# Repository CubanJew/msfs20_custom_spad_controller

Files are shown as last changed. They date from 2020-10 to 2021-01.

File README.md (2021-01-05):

# msfs20_custom_spad_controller
Microsoft Flight Simulator 2020 - Custom Flight Panel Controller

### Description:
Custom control panel for Microsoft Flight Simulator 2020 using SPAD.neXt as interface between game and Arduino microcontroller. Designed with A320 in mind. Panel is meant to be mounted to the side of Logitech G Flight Simulator Panel bracket. 

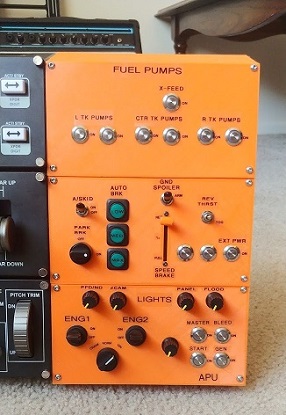
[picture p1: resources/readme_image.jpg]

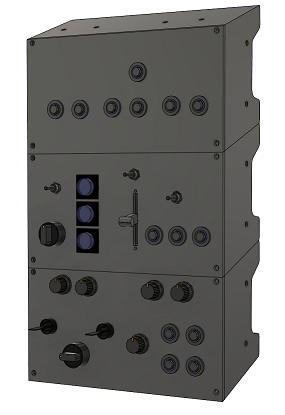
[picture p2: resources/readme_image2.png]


Supports:
- **17 pushbutton with LED** (LED is controlled by state of control in the game).
	_[fuel pumps 1-6, cross-feed pump, APU-master, APU-start, APU-bleed air, APU-gen, external power, auto-brake level control (low + med + max), x2 TBD (spare)]_
	
- **5 toggle switches**
	_[anti-skid, ground spoiler arm, engine 1 + 2 master starters, reverse throttle toggle]_
	
- **2 selector switches**
	_[engine mode switch (crank/normal/ignition), parking break]_
- **6 potentiometers** (5 rotary + 1 slide)
	_[lights: PFD/ND/FD, ECAM, flood, panel, x1 TBD (spare);  speed brake (slide pot)]_
- **1 foot pedal switch**
	_[brake pedals]_

Control board utilizes x3 MCP23017 I2C I/O expander ICs to provide control over 48 distinct inputs/outputs with just 2 Arduino pins. For LED outputs, each MCP23017 I/O pin is connected to an LED with a series resistor. For button inputs, each button is connected directly to an MCP23017 I/O pin, with an internal pull-up resistor enabled via software. All buttons are daisy-chained to ground on one side, and therefore no additional components are necessary for handling button inputs. Note that the pushbutton LEDs are controlled independently of the pushbutton meaning that the LED light state will reflect the state of the respective control in the game whether you cycle the control in the game or via the control panels physical button. The Arduino microcontrller handles detecting button presses and controls LED lights, and utilizes a 2-way serial connection with SPAD.neXT to interface with the game. 

### Installation Instructions:
1. Build the control interface board by following [schematics](https://github.com/CubanJew/msfs20_custom_spad_controller/blob/main/Hardware/Electrical/Schematic.pdf).

2. 3D print STL files located in `/Hardware/Panel 3D Files/STL/`. You will need 3 Brackets, 1 Slide Potentiometer Lever Hat, and one of each of the three faceplates. Use soldering iron to heat insert four M3-4mm knurled brass inserts into each bracket's corner faceplate mounting holes and secure each faceplate to bracket with four M3-6mm bolts. Note that bracket top mounting holes are misaligned relative to the bottom mounting holes. If you wish to attach the three brackets vertically, drill new upper mounting holes to 2 of 3 the brackets. Bracket mounting hole alignment will be fixed in future. 

3. Install buttons/potentiometers on to faceplate holes (note: you will need to use a deburring tool to slightly enlarge the component holes as there is very little tolerance) and wire up connections between panel and control interface board. Daisy-chain switch/pot grounds together for each panel. Refer to [Bill of Materials](https://github.com/CubanJew/msfs20_custom_spad_controller/blob/main/Hardware/Bill%20of%20Materials.txt) for parts information. Reference [I/O connection summary table](https://github.com/CubanJew/msfs20_custom_spad_controller/blob/main/Hardware/Electrical/IO%20Table.JPG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) and [schematic](https://github.com/CubanJew/msfs20_custom_spad_controller/blob/main/Hardware/Electrical/Schematic.pdf).

4. To upload microcontroller firmware, install PlatformIO IDE and add `/Software/AVR/FLIGHT SIM SPAD INTERFACE/` as new folder project. Upload code to your Arduino Pro Micro. 

5. Add control interface board to SPAD.neXt as a new Serial device to SPAD.neXt under settings->Devices->Serial Devices->"Add New Device" with the following settings:

	> Serial Port = = your USB COM port
	
	> Speed = 115200
	
	> Enable DTR = ON
	
	> 32 Bit = OFF
	
   Save settings and restart SPAD.neXt. Verify control interface board serial device is connected to SPAD.neXt by going to panels->SERIAL COMXX and selecting "Show Log". If it is not connected press "Connect".
   
6. Add each of the scripts included in `/Software/SPAD.next Configuration/` folder to SPAD.neXt script panel.

7. If you have flybywiresim's "A32NX" mod installed you will need to update the mod's light potentiometer indices in order to make the light potentiometers work [(reference)](https://github.com/flybywiresim/a32nx/issues/1202). Install Autohotkey and run script named `A32NX Pot ID Fix.ahk`located in `/Software/A32NX Pot ID Fix/`

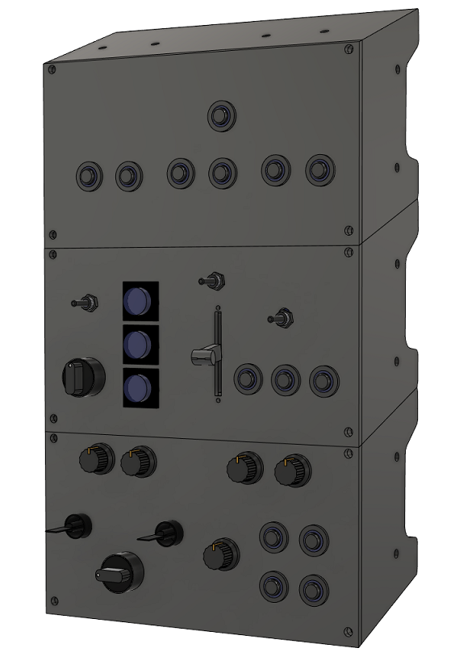
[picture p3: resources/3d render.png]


References:

- [Fusion 360 3D Design File](https://a360.co/2SDgtfb) or `/Hardware/Panel 3D Files/FLIGHT SIM COCKPIT v27.f3d`
- [Schematic](https://github.com/CubanJew/msfs20_custom_spad_controller/blob/main/Hardware/Electrical/Schematic.pdf)
- [I/O Reference Table](https://github.com/CubanJew/msfs20_custom_spad_controller/blob/main/Hardware/Electrical/IO%20Table.JPG) 
- [Bill of Material](https://github.com/CubanJew/msfs20_custom_spad_controller/blob/main/Hardware/Bill%20of%20Materials.txt)
- [Project Photo Gallery](https://imgur.com/a/4q6AOHk)

Notes:
1. Faceplate component holes do not have much tolerance; you will need to use a debururing to slightly enlarge the holes. 
2. The size of the microcontroller firmware is large relative to flash program memory of the Arduino Pro Micro. As such, many repeated firmware uploads may randomly corrupt the bootloader. You will need another Arduino or an AVR programmer to reupload the bootloader to allow firmware uploading from your IDE.  

To-do list:
- Fix bracket top mounting hole alignment.
- Combine ground spoiler arm toggle switch and speed brake slide potentiometer into a single physical component.
- Add logic to force game's initial state of anti-skid, ground spoiler arm, and parking brake to match control board when controller is first connected.
- Implement spare 2 buttons and 1 potentiometer on panel. 
- Fabricate front faceplates with backlit labels using http://www.frontpanelexpress.com/ 
- Clean up code
- PWM brightness control for LEDs

Version History:
- 10/14/20: Initial release
- 01/05/21: Update valve indices due to game update for fuel x-feed (from 1 to 3) pushbutton & LED [main.cpp, digital.cpp]; ENG1 & ENG2 MASTER SWITCH (from 6 & 7 to 1 & 2, respectively) SPAD scripts [ENG1 MASTER SW.xml, ENG2 MASTER SW.xml]

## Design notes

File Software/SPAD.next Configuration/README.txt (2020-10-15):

Copy the included scripts in this folder to SPAD.neXt.

These SPAD.neXt scripts are required due to:

1. Ensure fidelity between control state in-game with physical toggle button.

	... or ...

2. Because multiple simulation events are required for a particular digital input (e.g., foot brake pedal).

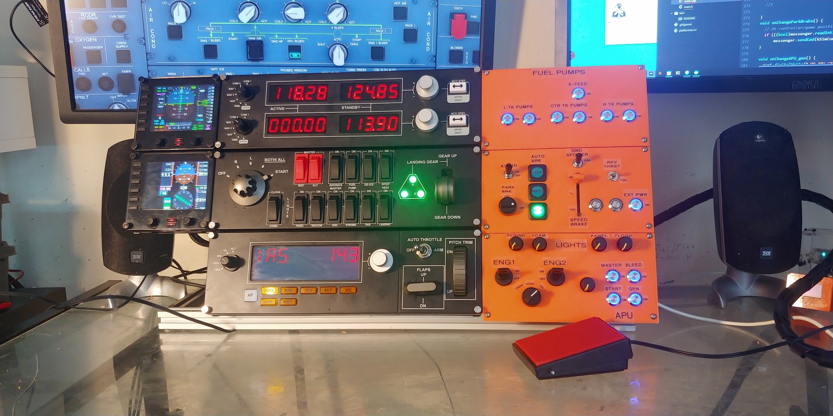
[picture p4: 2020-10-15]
resources/_FINAL - Overview with Lights.jpg

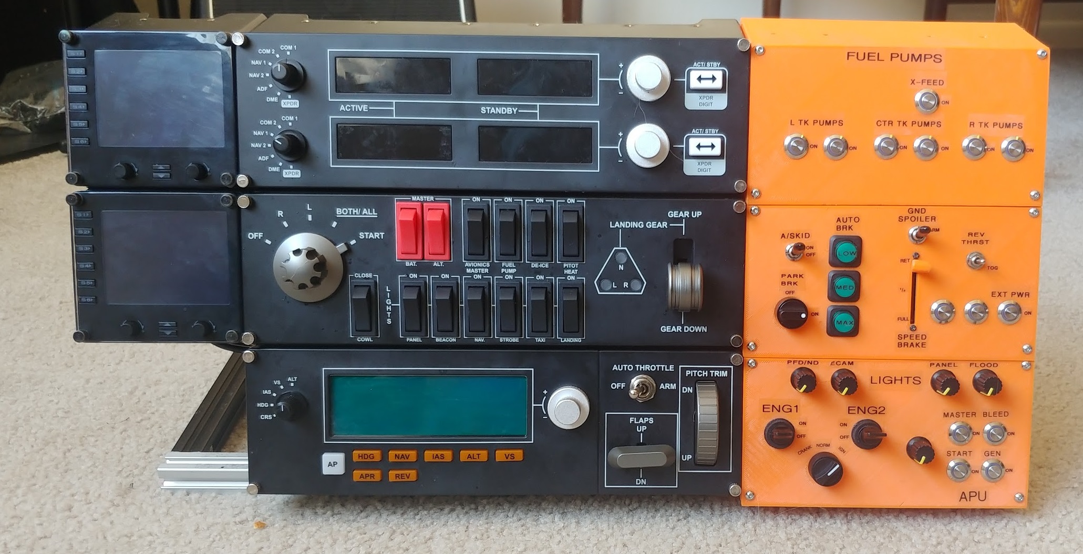
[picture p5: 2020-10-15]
resources/_FINAL - Overview.jpg

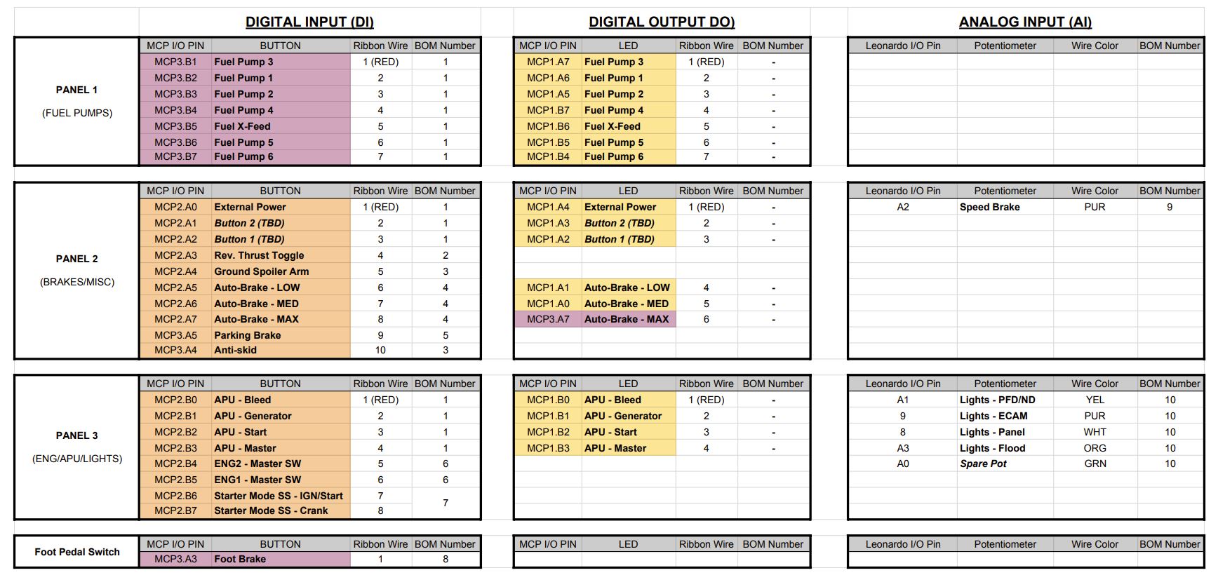
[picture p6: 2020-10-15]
Hardware/Electrical/IO Table.JPG

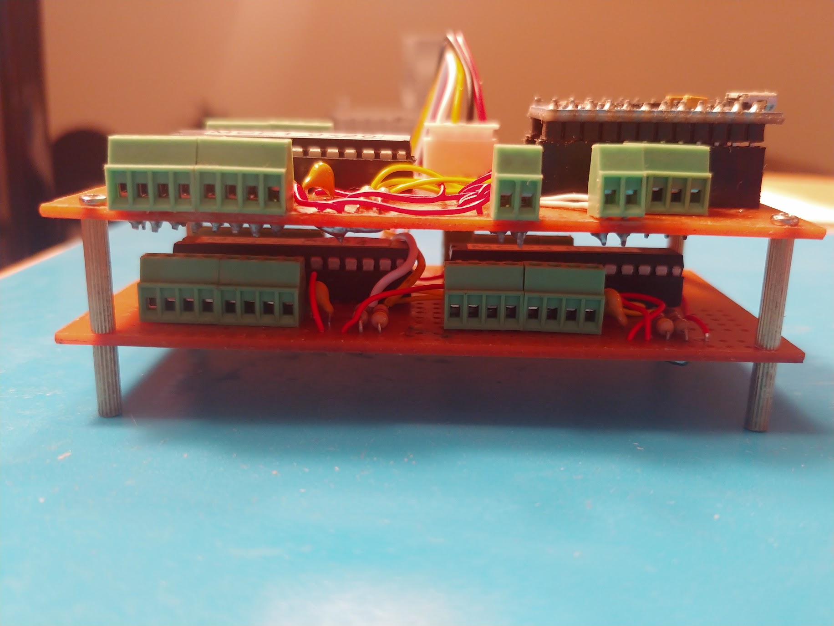
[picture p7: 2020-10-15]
resources/Control Board-2.jpg

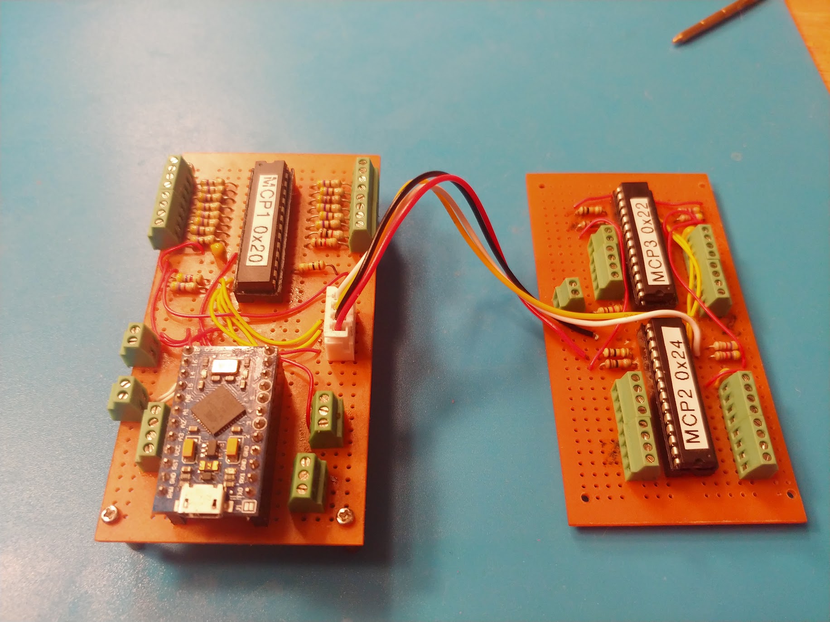
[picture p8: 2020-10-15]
resources/Control Board-1.jpg

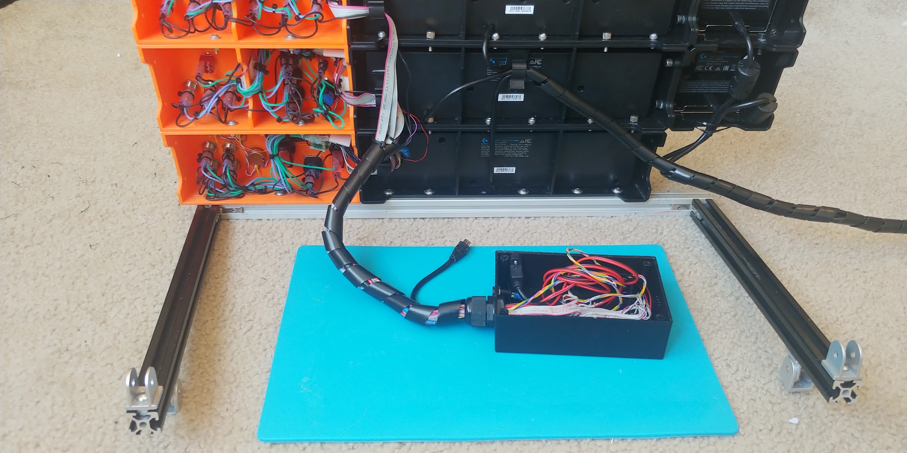
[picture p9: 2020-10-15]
resources/Enclosure Box.jpg

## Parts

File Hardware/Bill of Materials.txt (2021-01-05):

Panel Controls (see "/Hardware/Electrical/IO Table.jpg" for BOM # cross-reference):
--------------------------------------------------------------------------------------------------------------------------------------------------------------------------------------------
BOM #	QTY	Description										Model						Link
1	14	12mm Blue LED Momentary SPST-1NO Pushbutton 4-Pin 3VDC					SKU CP.QM.940-C					https://www.ebay.com/p/925617176
2	1	Mini Toggle (Momentary) Switch DPDT 3-Position 6-Pin ON/OFF/ON 6mm mount hole		Generic						https://www.amazon.com/Twidec-Momentary-Miniature-Waterproof-MTS-223-MZ/dp/B07VK46JQ3
3	2	Mini Toggle Switch 2-position Maintained ON-ON SPDT 3Pin Flat Handle 6.35mm mount hole	SH T8013-UHB / generic				https://www.amazon.com/T8013-UHB-Handle-Maintained-Position-Toggle/dp/B07M5M8DT8
4	3	16mm Green LED Momentary SPST-1NO Pushbutton 4-Pin 3VDC					Uxcell UPC 608641347241 / Model R16-503/BD	https://www.amazon.com/uxcell-Green-Momentary-Button-Switch/dp/B008ZYD3TI
5	1	16mm 2-Position Latching Rotary Selector Switch SPDT-1NO-1NC				Uxcell UPC A17052700ux0245			https://www.amazon.com/gp/product/B078M9KPN8/
6	2	2-Position Switch SPST 0.5" hole							Calterm Switch Duckbill 20A 40090 / generic	https://www.amazon.com/Calterm-40090-Switch-Duckbill-Black/dp/B000CINK70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
7	1	16mm 3-Position Latching Maintained Rotary Selector Switch 2NO-2NC			Taiss LA16-11X31 (ASIN B07GWN5X4T)		https://www.amazon.com/gp/product/B07GWN5X4T
8	1	Momentary Foot Switch									Philmore LKG p/n 30-17090			https://www.amazon.com/gp/product/B004GIIYK0
		1/4" TRS to 3.5mm headphone jack adapter						MillSO ASIN B07SRWZ77L				https://www.amazon.com/gp/product/B07SRWZ77L
		3.5mm Female Panel Mount Headphone Jack "						Generic / Philmore 70-534			https://www.amazon.com/Philmore-Isolated-Stereo-Female-Headphone/dp/B00OGLCR3W							
9	1	Slide Potentiometer 10K Ohm								TT Electronics/BI p/n PS30-10PB10BR10K		https://www.mouser.com/ProductDetail/BI-Technologies-TT-Electronics/PS30-10PB10BR10K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
10	5	100K Ohm Linear Taper Rotary Potentiometer 3-pin 15mm shaft				Generic						https://www.amazon.com/HiLetgo-Single-Joint-Potentiometer-Variable-Resistors/dp/B07VJYH29F

Panel Hardware	
---------------------------------------------------------------------------------------------------------------------------------------------------------------------------------------------
QTY	Description
12	M3 6mm bolts
12	M3 4mm height knurled brass insert

Control board:
---------------------------------------------------------------------------------------------------------------------------------------------------------------------------------------------
Qty	Description
1	Arduino Pro Micro 5V 16 MHz
3	MCP23017 + 28-pin 2.54mm DIP Socket
6	Resistor - 4.7 kOhm
3	Resistor - 1 kOhm
14	Resistor - 470 Ohm
5	Resistor - 10 kOhm
3	Capacitor - 0.1 uF (Ceramic)
1	Capacitor - 10 uF (Electrolytic)
2	12 Pin Female Header Pins 2.54" pitch
6	8-pin Screw Terminal Block 2.54mm pitch
1	6-pin Screw Terminal Block 2.54mm pitch
1	2-pin Screw Terminal Block 2.54mm pitch
1	4-pin Screw Terminal Block 2.54mm pitch
A.R.	Wire
A.R.	Standoffs
A.R.	Perfboard
Opt	Micro USB Panel Mount cable 			https://www.amazon.com/gp/product/B07BK4WZV9/

* A.R. = As-required
* Opt. = Optional

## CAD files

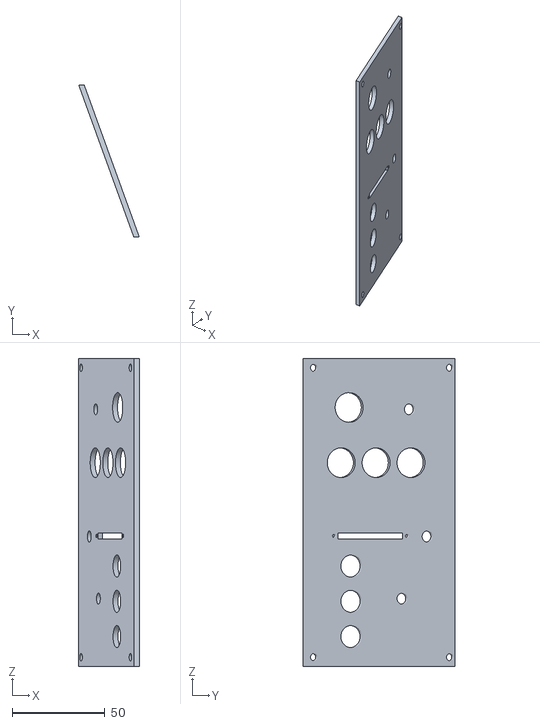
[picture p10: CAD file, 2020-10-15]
Hardware/Panel 3D Files/STL/Faceplate - Panel 2 - BRAKE MISC.stl
32.8 x 82.1 x 166.0

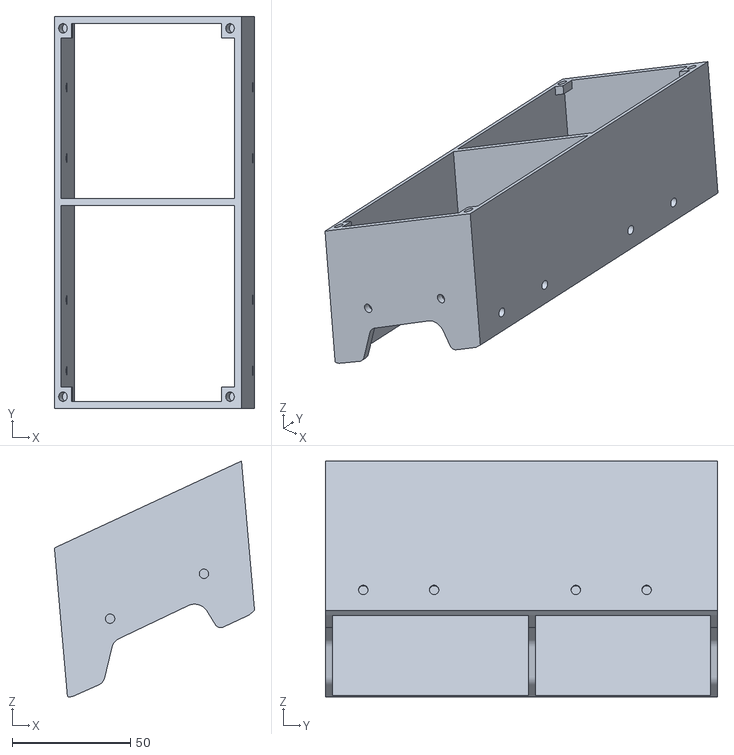
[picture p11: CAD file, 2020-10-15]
Hardware/Panel 3D Files/STL/Bracket.stl
84.8 x 166.0 x 99.9

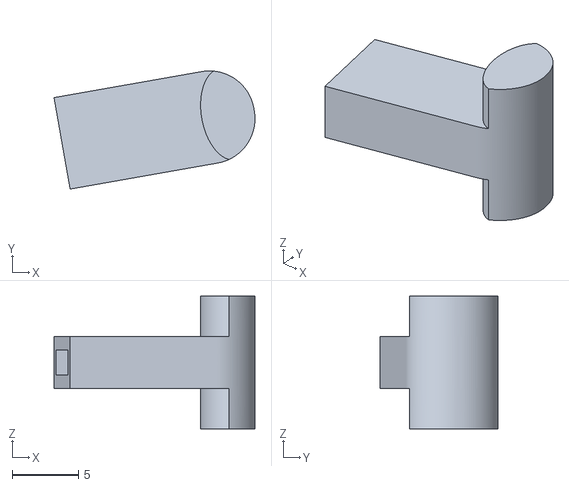
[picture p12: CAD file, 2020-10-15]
Hardware/Panel 3D Files/STL/Slide Potentiometer Lever Hat.stl
15.2 x 8.91 x 10.0

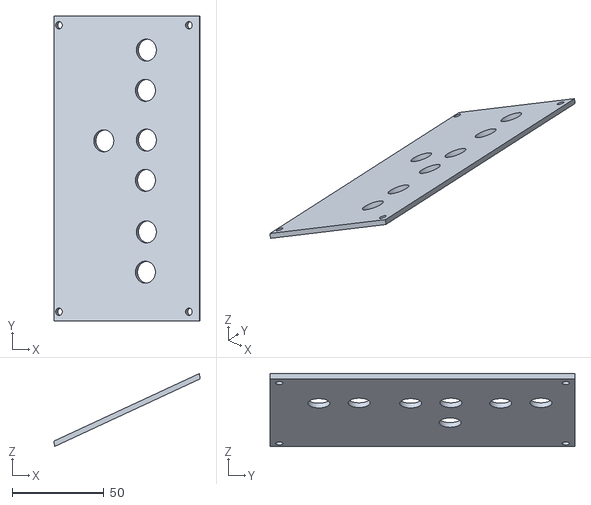
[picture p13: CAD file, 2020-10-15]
Hardware/Panel 3D Files/STL/Faceplate - Panel 1 - FUEL.stl
79.5 x 166.0 x 39.8

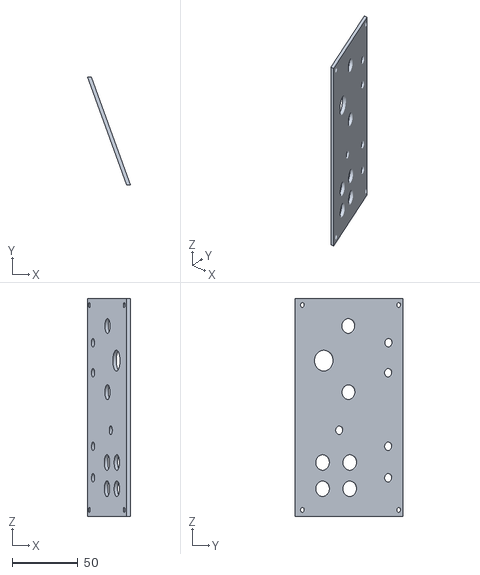
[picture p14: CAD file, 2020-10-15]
Hardware/Panel 3D Files/STL/Faceplate - Panel 3 - ENG APU LIGHTS.stl
32.8 x 82.1 x 166.0

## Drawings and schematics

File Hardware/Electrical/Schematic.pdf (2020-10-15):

A

A

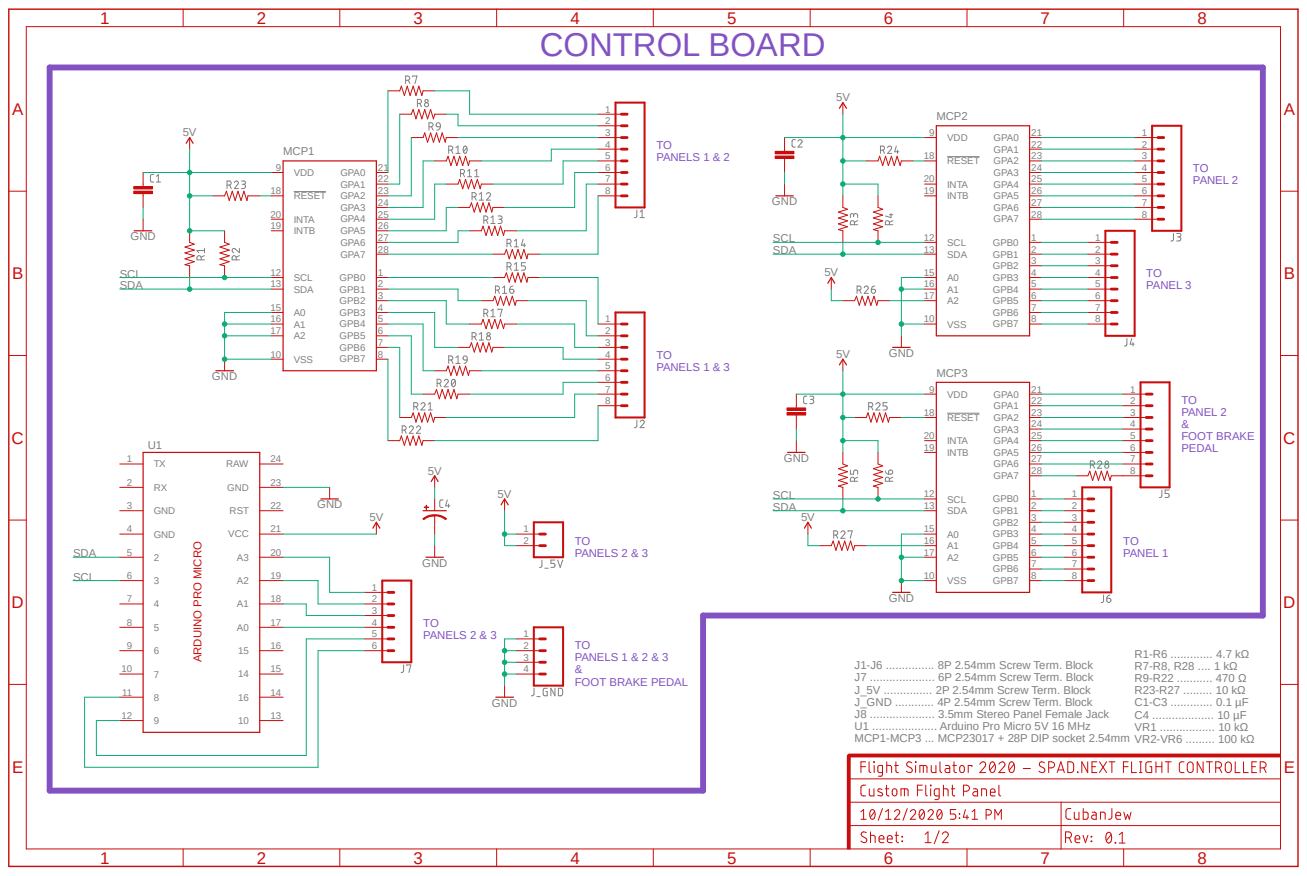
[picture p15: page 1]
GND; SCL 12; SDA 13; RESET 18; INTA 20; INTB 19; GPB0; 1 GPB1; 2 GPB2; 3 GPB3; 4 GPB4; 5 GPB5; 6 GPB6; 7 GPB7; 8 GPA0; 21 GPA1; 22 GPA2; 23 GPA3; 24 GPA4; 25 GPA5; 26 GPA6; 27 GPA7; 28 VDD 9; VSS 10 MCP1; VSS 10 MCP2; VSS 10 MCP3; 20 VCC; 21 RST; 22 GND; 23 RAW; GND 4; GND 3; SCL; SDA; ARDUINO PRO MICRO; CONTROL BOARD; TO PANELS 1 & 2; TO PANELS 1 & 3; TO PANEL 2; TO PANEL 3; TO PANEL 2 & FOOT BRAKE PEDAL; TO PANEL 1; TO PANELS 2 & 3; TO PANELS 1 & 2 & 3 & FOOT BRAKE PEDAL

J1-J6 ............... 8P 2.54mm Screw Term. Block
J7 .................... 6P 2.54mm Screw Term. Block
J_5V ............... 2P 2.54mm Screw Term. Block
J_GND ............ 4P 2.54mm Screw Term. Block
J8 .................... 3.5mm Stereo Panel Female Jack
U1 .................... Arduino Pro Micro 5V 16 MHz
MCP1-MCP3 ... MCP23017 + 28P DIP socket 2.54mm

A

A

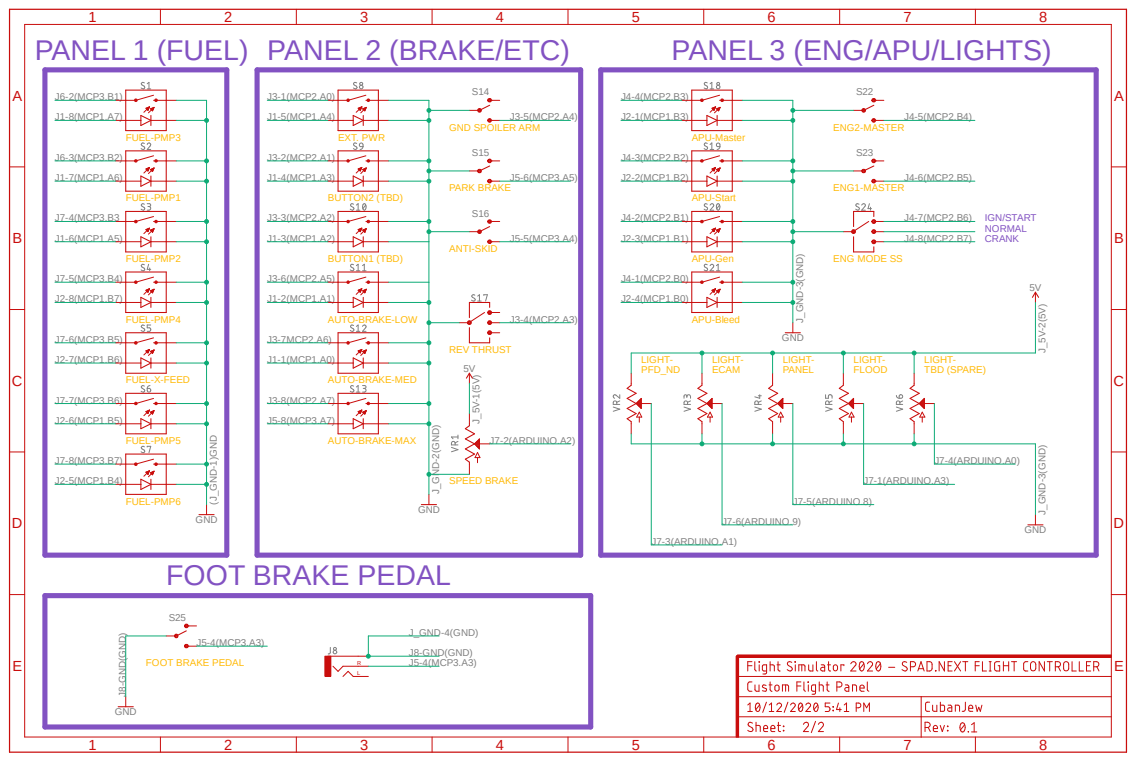
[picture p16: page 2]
J_GND-4(GND); GND; J6-2(MCP3.B1); J1-8(MCP1.A7); J6-3(MCP3.B2); J1-7(MCP1.A6); J7-4(MCP3.B3; J1-6(MCP1.A5); J7-5(MCP3.B4); J2-8(MCP1.B7); J7-6(MCP3.B5); J2-7(MCP1.B6); J7-7(MCP3.B6); J2-6(MCP1.B5); J7-8(MCP3.B7); J2-5(MCP1.B4); J3-1(MCP2.A0); J1-5(MCP1.A4); J3-2(MCP2.A1); J1-4(MCP1.A3); J3-3(MCP2.A2); J1-3(MCP1.A2); J3-6(MCP2.A5); J1-2(MCP1.A1); J3-7MCP2.A6); J1-1(MCP1.A0); J3-8(MCP2.A7); J5-8(MCP3.A7); J3-5(MCP2.A4); J5-6(MCP3.A5); J5-5(MCP3.A4); J3-4(MCP2.A3); J7-2(ARDUINO.A2); J4-4(MCP2.B3)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

PANEL 1 (FUEL) PANEL 2 (BRAKE/ETC)

PANEL 3 (ENG/APU/LIGHTS)

GND SPOILER ARM

ENG MODE SS

AUTO-BRAKE-LOW

AUTO-BRAKE-MED

AUTO-BRAKE-MAX

GND
FOOT BRAKE PEDAL

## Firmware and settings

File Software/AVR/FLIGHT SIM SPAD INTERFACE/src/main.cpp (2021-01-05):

#include <Arduino.h>
#include "main.h"
#include "global.h"

CmdMessenger messenger(Serial);
Adafruit_MCP23017 mcp1, mcp2, mcp3;

AUTOBRAKE_SELECTED autobrakeSetting = BRAKE_OFF;
bool antiskid_en = false;
bool autoBrake_en = false;
bool isReady = false;

extern BUTTON buttons_1[], buttons_2[];

// LIMITATIONS:
/**

  TODO: A/SKID LOGIC CHECK AGAINST GAME STATE
  cHANGING aUTO BRAKE LEVEL CONTROL IN GAME will not update
*/

void setup() {
  Serial.begin(115200);
  init_AnalogPins();
  init_DigitalPins();

  initDIButtonMap();
  attachCommandCallbacks();
  // SIMCONNECT:STEERING_SET
}

void loop() {
  scanDigitalInputs();
  scanAnalogInputs();
  messenger.feedinSerialData();   // Process incoming serial data, and perform callbacks
  delay(100);

}


String getPStr(int index) {
  char cmd[_PSTR_BUFFER_SIZE];
  strcpy_P(cmd, (char*)pgm_read_word(&(PSTR_TABLE_CMDs[index]))); // Necessary casts and dereferencing, just copy.
  return String(cmd);
}
// special logic for keeping track of auto brake control level light status./
// Need's SUB'd to SIMCONNECT:ANTISKID BRAKES ACTIVE and
void digitalWriteAutoBrakeLEDs (AUTOBRAKE_SELECTED brakeLevel)
{
  mcp1.digitalWrite(P_DO_AUTOBRAKE_LO_LED, LOW);
  mcp1.digitalWrite(P_DO_AUTOBRAKE_MED_LED, LOW);
  mcp3.digitalWrite(P_DO_AUTOBRAKE_MAX_LED, LOW);

  // AUTO BRAKE level already set in-game (no way to access data)
  if (!autoBrake_en || brakeLevel == BRAKE_OFF) {
    autobrakeSetting = BRAKE_OFF;
  }
  // ANTI-SKID switch permissive to set brake level
  if (antiskid_en)
  {
    // handle toggle off overrides
    if (brakeLevel == BRAKE_LO) {
      if (autobrakeSetting == BRAKE_LO) { // already set to LOW; turn off LED
        mcp1.digitalWrite(P_DO_AUTOBRAKE_LO_LED, LOW);
        autobrakeSetting = BRAKE_OFF;
      } else {
        mcp1.digitalWrite(P_DO_AUTOBRAKE_LO_LED, HIGH);
        autobrakeSetting = BRAKE_LO;
      }
    } else if (brakeLevel == BRAKE_MED) {
      if (autobrakeSetting == BRAKE_MED) {
        mcp1.digitalWrite(P_DO_AUTOBRAKE_MED_LED, LOW);
        autobrakeSetting = BRAKE_OFF;
      } else {
        mcp1.digitalWrite(P_DO_AUTOBRAKE_MED_LED, HIGH);
        autobrakeSetting = BRAKE_MED;
      }

    } else if (brakeLevel == BRAKE_MAX) {
      if (autobrakeSetting == BRAKE_MAX) {
        mcp3.digitalWrite(P_DO_AUTOBRAKE_MAX_LED, LOW);
        autobrakeSetting = BRAKE_OFF;
      } else {
        mcp3.digitalWrite(P_DO_AUTOBRAKE_MAX_LED, HIGH);
        autobrakeSetting = BRAKE_MAX;
      }
    }
  }
  int brakeArg;
  if (autobrakeSetting == BRAKE_OFF)
    brakeArg = 1;
  else if (autobrakeSetting == BRAKE_MAX)
    brakeArg = 4; //buttons[4].arg;
  else if (autobrakeSetting == BRAKE_MED)
    brakeArg = 3; //buttons[5].arg;
  else if (autobrakeSetting == BRAKE_LO)
    brakeArg = 2; //buttons[6].arg;
  // NOTE: _CMD_PROVIDER IS PROBABLY BROKEN
  messenger.sendCmdStart(kSimCommand);  //buttons[ipstr_abrakeControlLevel].id);
  messenger.sendCmdArg("SIMCONNECT:" + getPStr(ipstr_abrakeControlLevel));  //_CMD_PROVIDER(ipstr_abrakeControlLevel));   //buttons[i].cmd_on);
  messenger.sendCmdArg(brakeArg);  // OFF -> SET_AUTOBRAKE_CONTROL=1
  messenger.sendCmdEnd();
}


void processChangeCommands(BUTTON * buttons) {
  for (int i = 0; i < 16; i++)
  {
    if ((buttons[i].id != kINVALID) && (buttons[i].change))
    {
      // MOMENTARY BUTTON PRESSED
      if (buttons[i].type == _PB_MOM && buttons[i].currentVal == 1)
      {
        //messenger.sendCmd(buttons[i].id, buttons[i].cmd_on);
        // SPECIAL CASE for auto-brake lights logic (button elements 4-6). Handle command seperately!
        if (buttons[i].cmdIndex == ipstr_abrakeControlLevel && buttons[i].arg == 4)
          digitalWriteAutoBrakeLEDs(BRAKE_MAX);   // high
        else if (buttons[i].cmdIndex == ipstr_abrakeControlLevel && buttons[i].arg == 3)
          digitalWriteAutoBrakeLEDs(BRAKE_MED);  // med
        else if (buttons[i].cmdIndex == ipstr_abrakeControlLevel && buttons[i].arg == 2)
          digitalWriteAutoBrakeLEDs(BRAKE_LO);   // low
        else
        {
          // below probably needss fixed
          if (buttons[i].arg == -999) // no argument
          {
            messenger.sendCmd(buttons[i].id, _CMD_PROVIDER(i));
          } else {
            messenger.sendCmdStart(buttons[i].id);
            messenger.sendCmdArg(_CMD_PROVIDER(i));   //buttons[i].cmd_on);
            messenger.sendCmdArg(buttons[i].arg);
            messenger.sendCmdEnd();
          }
        }


        // TOGGLE PUSHBUTTON
      } else if (buttons[i].type == _TOGGLE)
      {
        // ... TOGGLE BUTTON STATE CHANGE - SUBSCRIBED DATAE
          if (buttons[i].id != kSimCommand)
          {
            messenger.sendCmd(buttons[i].id, buttons[i].currentVal);
            // ... TOGGLE BUTTON STATE CHANGE - SEND VALUE
          }
          else if (buttons[i].id == kSimCommand)
          {
            messenger.sendCmd(kSimCommand, getPStr(buttons[i].cmdIndex));  //cmd_on);

          }
      // BINARY SWITCH BUTTON
      } else if (buttons[i].type == _BINARY)
      {
        // LOCAL PROVIDER MEANS LOGIC HANDLE BY SPAD (SPAD SCRIPTED EVENT PERFORMS LOGIC ON LOCAL DEVICE VARIABLE SUB)
        if(buttons[i].provider == LOCAL)
        {
          switch (buttons[i].id)
          {
            // ENG1/ENG2 STARTERS: SPAD scripted event actions:
            // CONDITION:
            //   CJ Custom Panel:SWITCHES/ENG1_STARTER_MASTER = 1 or -1
            //   CJ Custom Panel:SWITCHES/ENG2_STARTER_MASTER = 1 or -1
            //      (use 1/-1 for on/off so SPAD can distinguish from disconnection when value defaults to 0)
            // ACTIONS:
            //    TURN ON:
            //        SIMCONNECT:TOGGLE_STARTER1 [arg=0]
            //        MSFS:FUELSYSTEM_VALVE_OPEN [arg=6 for ENG 1; 7 for ENG 2]
            //    TURN OFF:
            //        SIMCONNECT:TOGGLE_STARTER1 [arg=0]
            //        MSFS:FUELSYSTEM_VALVE_CLOSE [arg=6 for ENG 1; 7 for ENG 2]

            // @TODO: HANDLE LOGIC FOR GAME/LOCAL MISMATCH
            case kLOCAL_ENG_MST_STARTER_1:
                messenger.sendCmd(kLOCAL_ENG_MST_STARTER_1, !buttons[i].currentVal == 0 ? -1 : 1);
                break;
            case kLOCAL_ENG_MST_STARTER_2:
                messenger.sendCmd(kLOCAL_ENG_MST_STARTER_2, !buttons[i].currentVal == 0 ? -1 : 1);
                break;

                // ENGINE MODE SELECTOR SWITCH  SPAD scripted event actions:
                // CONDITION:
                //    CJ Custom Panel:SWITCHES/ENG1_STARTER_MASTER = 1 or -1
                //    CJ Custom Panel:SWITCHES/ENG2_STARTER_MASTER = 1 or -1
                // ACTIONS:
                //    TURN ON:
                //        SIMCONNECT:TOGGLE_STARTER1 [arg=0]
                //        MSFS:FUELSYSTEM_VALVE_OPEN [arg=6 for ENG 1; 7 for ENG 2]
                //    TURN OFF:
                //        SIMCONNECT:TOGGLE_STARTER1 [arg=0]
                //        MSFS:FUELSYSTEM_VALVE_CLOSE [arg=6 for ENG 1; 7 for ENG 2]
            case kLOCAL_ENG_MODE_SS_POS_CRANK:
                messenger.sendCmd(kLOCAL_ENG_MODE_SS_POS_CRANK, buttons[i].currentVal);
                break;
            case kLOCAL_ENG_MODE_SS_POS_START:
                messenger.sendCmd(kLOCAL_ENG_MODE_SS_POS_START, buttons[i].currentVal);
                break;

                // BRAKE PEDAL  SPAD scripted event actions:
                // (use SPAD logic due to 2 simulation event calls required for left/right brake)
                // CONDITION:
                //    CJ Custom Panel:SWITCHES\BRAKE = 1 or 0
                //
                // ACTIONS:
                //    TURN ON:
                //        SIMCONNECT:AXIS_LEFT_BRAKE_SET [arg=16383]
                //        SIMCONNECT:AXIS_RIGHT_BRAKE_SET [arg=16383]
                //    TURN OFF:
                //        SIMCONNECT:AXIS_LEFT_BRAKE_SET [arg=0]
                //        SIMCONNECT:AXIS_RIGHT_BRAKE_SET [arg=0]
            case kLOCAL_BRAKE_POS:
                messenger.sendCmd(kLOCAL_BRAKE_POS, buttons[i].currentVal);
                break;


            // GROUND SPOILER ARM
            // (use SPAD logic to ensure fidelity between toggle switch and in-game state)
            // CONDITION:
            //    CJ Custom Panel:SWITCHES\GND_SPOILER_ARM = 1 or -1
            //
            // ACTIONS:
            //    TURN ON:
            //        SIMCONNECT:SIMCONNECT:SPOILERS_ARM_SET [arg=1]
            //    TURN OFF:
            //        SIMCONNECT:SIMCONNECT:SPOILERS_ARM_SET [arg=0]

            case kLOCAL_GND_SPOILER_ARM:
                messenger.sendCmd(kLOCAL_GND_SPOILER_ARM, buttons[i].currentVal == 1 ? 1 : -1);
                break;

            // ANTISKID
            // (use SPAD logic to ensure fidelity between toggle switch and in-game state)
            // CONDITION:
            //    CJ Custom Panel:SWITCHES\ANTISKID = 1 or -1
            //
            // ACTIONS:
            //    TURN ON:
            //       SET SIMCONNECT:"ANTISKID BRAKES ACTIVE" = 1
            //    TURN OFF:
            //       SET SIMCONNECT:"ANTISKID BRAKES ACTIVE" = 0
            case kLOCAL_ANTISKID:
                messenger.sendCmd(kLOCAL_ANTISKID, buttons[i].currentVal == 1 ? 1 : -1);
                break;



            // PARK BRAAKE
            // (use SPAD logic to ensure fidelity between toggle switch and in-game state)
            // CONDITION:
            //    CJ Custom Panel:SWITCHES\xxxx = 1 or -1
            //
            // ACTIONS:
            //    TURN ON:
            //       SIMCONNECT:"PARKING_BRAKES" [arg=1]
            //    TURN OFF:
            //       SET SIMCONNECT:"PARKING_BRAKES" [arg=0]
            case kLOCAL_PARK_BRAKE:
                messenger.sendCmd(kLOCAL_PARK_BRAKE, buttons[i].currentVal == 1 ? -1 : 1); // inverted value (too l;azy to fix wiring)
                messenger.sendCmd(kSimCommand, getPStr(ipstr_parkbrake));
                // @ TODO: CHANGE 0 BACK TO -1 ?
                break;


          }
        } else
        {
          messenger.sendCmdStart(kSimCommand);
          messenger.sendCmdArg(getPStr(buttons[i].cmdIndex));   //_CMD_PROVIDER(ipstr_abrakeControlLevel));   //buttons[i].cmd_on);
          messenger.sendCmdArg(buttons[i].currentVal);  // OFF -> SET_AUTOBRAKE_CONTROL=1
          messenger.sendCmdEnd();
            //messenger.sendCmd(buttons[i].id, buttons[i].currentVal);
            //DEBUG_P(Serial.println("*" + buttons[i].currentVal ? buttons[i].cmd_on : buttons[i].cmd_off));
        }
      }
      buttons[i].change = false;
    }
  }
}


void onChangeFP1() {
  mcp1.digitalWrite(P_DO_FUEL_PMP_LT_1_LED, messenger.readInt32Arg());
}
void onChangeFP2() {
  mcp1.digitalWrite(P_DO_FUEL_PMP_LT_2_LED, messenger.readInt32Arg());
}
void onChangeFP3() {
  mcp1.digitalWrite(P_DO_FUEL_PMP_CT_1_LED, messenger.readInt32Arg());
}
void onChangeFP4() {
  mcp1.digitalWrite(P_DO_FUEL_PMP_CT_2_LED, messenger.readInt32Arg());
}
void onChangeFP5() {
  mcp1.digitalWrite(P_DO_FUEL_PMP_RT_1_LED, messenger.readInt32Arg());
}
void onChangeFP6() {
  mcp1.digitalWrite(P_DO_FUEL_PMP_RT_2_LED, messenger.readInt32Arg());
}
void onChangeFuelXFeed() {
  mcp1.digitalWrite(P_DO_FUEL_XFEED_LED, messenger.readInt32Arg());
}

void onChangeAntiSkidBrake()
{

  int tmpVal = (bool)messenger.readInt32Arg();
  // On controller/game state mismatch, force game to align with physical button state
  if (tmpVal != buttons_2[P_DI_ANTISKID].currentVal)
  {
    messenger.sendCmd(kLOCAL_ANTISKID,        buttons_2[P_DI_ANTISKID].currentVal == 1 ? 1 : -1);
    return;
  }

  antiskid_en = tmpVal; //(bool)messenger.readInt32Arg();
  // if antiskid disabled, turn off brake level control level
  if (!antiskid_en)
    digitalWriteAutoBrakeLEDs(BRAKE_OFF);
}
// LOCAL LOGIC FOR AUTO BRAKE LEVEL CONTROL
void onChangeAutoBrakeCB() {
  //int val = messenger.readInt32Arg();
  // On controller/game state mismatch, force game to align with physical button state
  //int tmpVal = !(messenger.readInt32Arg());
  //if (tmpVal != buttons_2[P_DI_ANTISKID].currentVal)
  //{
  //    messenger.sendCmd(kLOCAL_ANTISKID, buttons_2[P_DI_ANTISKID].currentVal == 1 ? 1 : -1);
  //    return;
  //}

  autoBrake_en =  !(messenger.readInt32Arg());  // 0 = ON, 1 = OFF.

  // Currently no way to read Auto Braake Level control state from game.
  // If auto brake level control set in-gaame turn on all 3 auto-brake lights on as an UNKNOWN value condition
  //messenger.sendCmd(kDebug, String(String("GOT CB CHANGE-") + String(val)));
  //if (autoBrake_en )
  //  {
  //  mcp1.digitalWrite(P_DO_AUTOBRAKE_LO_LED, HIGH);
  //  mcp1.digitalWrite(P_DO_AUTOBRAKE_MED_LED, HIGH);
  //  mcp3.digitalWrite(P_DO_AUTOBRAKE_MAX_LED, HIGH);
  //}

}
void onChangeParkBrake() {
  // On controller/game position mismatch toggle game's park brake switch to force alignment
  boolean gameVal = (bool)messenger.readInt32Arg();
  if (gameVal != !buttons_2[P_DI_BRAKE_PARK].currentVal)
  {
     messenger.sendCmd(kSimCommand, getPStr(ipstr_parkbrake));
  }

  //String str = "loc=" + String(!buttons_2[P_DI_BRAKE_PARK].currentVal) + " event update=" + String(gameVal) + " send= ";
  //str += buttons_2[P_DI_BRAKE_PARK].currentVal == 1 ? "-1" : "1";

  //messenger.sendCmd(kDebug, str); // value inverted (too lazy to change wiring)
  //if (/*((bool)messenger.readInt32Arg()*/ gameVal != !buttons_2[P_DI_BRAKE_PARK].currentVal)  //](mcp3.digitalRead(P_DI_BRAKE_PARK)))) // mcp input inverted instead of changing wiring
    //messenger.sendCmd(kLOCAL_PARK_BRAKE, buttons_2[P_DI_BRAKE_PARK].currentVal == 1 ? -1 : 1); // value inverted (too lazy to change wiring)
//    messenger.sendCmd(kSimCommand, getPStr(ipstr_parkbrake));

}

void onChangeAPU_gen() {
  mcp1.digitalWrite(P_DO_APU_GEN_LED, messenger.readInt32Arg());

}
void onChangeAPU_bleed() {
  mcp1.digitalWrite(P_DO_APU_BLEED_LED, messenger.readInt32Arg() == 0 ? HIGH : LOW); // verify valrange (0-3)
}

void onChangeAPU_master() {
  mcp1.digitalWrite(P_DO_APU_MASTER_LED, messenger.readInt32Arg());
}

void onChangeExtPower() {
  mcp1.digitalWrite(P_DO_EXT_PWR_LED, messenger.readInt32Arg()); // verify valrange (0-3)

}

void onChangeEng1Master() {
  // On controller/game position mismatch toggle engine master switch
  int gameVal = messenger.readInt32Arg();
  if (gameVal != !mcp2.digitalRead(P_DI_ENG_MST_1))
    messenger.sendCmd(kLOCAL_ENG_MST_STARTER_1,!gameVal);

}
void onChangeEng2Master() {
  // On controller/game position mismatch toggle engine master switch
  int gameVal = messenger.readInt32Arg();
  if (gameVal != !mcp2.digitalRead(P_DI_ENG_MST_2))
    messenger.sendCmd(kLOCAL_ENG_MST_STARTER_2,!gameVal);
}

void onChangeStarter() {
  mcp1.digitalWrite(P_DO_APU_STARTER_LED, messenger.readInt32Arg()); // verify valrange (0-3)

}
void onChangeGNDSpoilerArm() {
  // On controller/game state mismatch, force game to align with physical button state
  int gameVal = messenger.readInt32Arg();
  if (gameVal != buttons_1[P_DI_SPOILER_ARM].currentVal)
    messenger.sendCmd(kLOCAL_GND_SPOILER_ARM, buttons_1[P_DI_SPOILER_ARM].currentVal == 1 ? 1 : -1);
}

void attachCommandCallbacks()
{
  // Attach callback methods - dont forget to sub below
  messenger.attach(onUnknownCommand);
  messenger.attach(kRequest  , onIdentifyRequest);
  messenger.attach(kFUEL_PMP1 , onChangeFP1);
  messenger.attach(kFUEL_PMP2 , onChangeFP2);
  messenger.attach(kFUEL_PMP3 , onChangeFP3);
  messenger.attach(kFUEL_PMP4 , onChangeFP4);
  messenger.attach(kFUEL_PMP5 , onChangeFP5);
  messenger.attach(kFUEL_PMP6 , onChangeFP6);
  messenger.attach(kFUEL_XFEED , onChangeFuelXFeed);
  messenger.attach(kAUTOBRAKE_CB_EN, onChangeAutoBrakeCB); // for auto brake light logic
  messenger.attach(kANTISKID, onChangeAntiSkidBrake);
  messenger.attach(kPARKBRAKE_POS, onChangeParkBrake);

  messenger.attach(kAPU_GEN_POS, onChangeAPU_gen);
  messenger.attach(kAPU_BLEED_POS, onChangeAPU_bleed);
  messenger.attach(kAPU_MASTER_POS, onChangeAPU_master);

  messenger.attach(kExtPower_POS, onChangeExtPower);

  messenger.attach(kENG1_Master_Pos, onChangeEng1Master);
  messenger.attach(kENG2_Master_Pos, onChangeEng2Master);

  messenger.attach(kAPU_STARTER, onChangeStarter);

  messenger.attach(kGND_Spoiler_Arm, onChangeGNDSpoilerArm);



}

// Called when a received command has no attached function
void onUnknownCommand()
{
}

void subscribeData(int channelID, PROVIDER provider, char * dataStr) {
  messenger.sendCmdStart(kCommand);
  messenger.sendCmdArg("SUBSCRIBE");
  messenger.sendCmdArg(channelID);
  messenger.sendCmdArg(provider ? "MSFS:" + String(dataStr) : "SIMCONNECT:" + String(dataStr));
  messenger.sendCmdEnd();
}

// Callback function to respond to indentify request. This is part of the
// Auto connection handshake.
void onIdentifyRequest()
{
  char *szRequest = messenger.readStringArg();

  if (strcmp(szRequest, "INIT") == 0) {
    messenger.sendCmdStart(kRequest);
    messenger.sendCmdArg("SPAD");
    // Unique Device ID: Change this!
    messenger.sendCmdArg(F("{DD7E3826-E439-4484-B186-F1443F3BC522}"));
    // Device Name for UI
    messenger.sendCmdArg("CJ Custom Panel");
    messenger.sendCmdEnd();
    return;
  }

  if (strcmp(szRequest, "PING") == 0) {
    messenger.sendCmdStart(kRequest);
    messenger.sendCmdArg("PONG");
    messenger.sendCmdArg(messenger.readInt32Arg());
    messenger.sendCmdEnd();
    return;
  }
  if (strcmp(szRequest, "CONFIG") == 0) {

    // SUBSCRIBE TO DATA
    // FUEL PUMP STATUS LIGHTS
    int pumpIDs[] = {2, 5, 1, 4, 3, 6}; // order of pump indicies left-to-right
    int pumpChannel[] =   {kFUEL_PMP1, kFUEL_PMP2, kFUEL_PMP3, kFUEL_PMP4, kFUEL_PMP5, kFUEL_PMP6}; // CMDID for exposed data to SPAD.neXt
    for (int i = 0; i < 6; i++)
      subscribeData(pumpChannel[i], MSFS,       ("FUELSYSTEM PUMP ACTIVE:" + String(pumpIDs[i])).c_str());

    subscribeData(kFUEL_XFEED,      MSFS,      "FUELSYSTEM VALVE SWITCH:3"); // FUEL X-FEED // was 1
    subscribeData(kANTISKID,        SIMCONNECT, getPStr(ipstr_antiskid).c_str()); //str_antiskid); // ANTI-SKID  (also needed for digitalWriteAutoBrakeLEDs())
    subscribeData(kAUTOBRAKE_CB_EN, SIMCONNECT, "AUTO BRAKE SWITCH CB"); // auto brake level control circuit breaker (needed for digitalWriteAutoBrakeLEDs())
    subscribeData(kPARKBRAKE_POS,   SIMCONNECT, getPStr(ipstr_parkBrakeState).c_str());
    // APU ...
    subscribeData(kAPU_GEN_POS,    SIMCONNECT, getPStr(ipstr_apuGenSwitchPos).c_str());
    subscribeData(kAPU_BLEED_POS,   SIMCONNECT, getPStr(ipstr_apuBleedSwitchPos).c_str());
    subscribeData(kAPU_MASTER_POS,   MSFS, getPStr(ipstr_apuMasterSwitchPos).c_str());

    subscribeData(kExtPower_POS,   MSFS, getPStr(ipstr_extPowerSwitchPos).c_str());

    subscribeData(kAPU_STARTER,   MSFS, "APU SWITCH");

    subscribeData(kGND_Spoiler_Arm,   SIMCONNECT, getPStr(ipstr_gndSpoilerArm).c_str());



    // expose LOCAL DEVICE variable for MASTER START SWITCH (spad scripted event handles logic) ...
    // ... ENG1-MASTER SWITCH & ENG2-MASTER SWITCH:
    exposeLocalDeviceVariable(kLOCAL_ENG_MST_STARTER_1, "switches/ENG1_STARTER_MASTER", "?", "?");
    exposeLocalDeviceVariable(kLOCAL_ENG_MST_STARTER_2, "switches/ENG2_STARTER_MASTER", "?", "?");
    // ... ENGINE MODE SELECTOR SWITCH:
    exposeLocalDeviceVariable(kLOCAL_ENG_MODE_SS_POS_CRANK, "switches/ENG_MODE_SS_CRANK", "?", "?");
    exposeLocalDeviceVariable(kLOCAL_ENG_MODE_SS_POS_START, "switches/ENG_MODE_SS_START", "?", "?");

    exposeLocalDeviceVariable(kLOCAL_BRAKE_POS, "switches/BRAKE", "?", "?");

    exposeLocalDeviceVariable(kLOCAL_GND_SPOILER_ARM, "switches/GND_SPOILER_ARM", "?", "?");

    exposeLocalDeviceVariable(kLOCAL_ANTISKID, "switches/ANTISKID", "?", "?");

    exposeLocalDeviceVariable(kLOCAL_PARK_BRAKE, "switches/PARK_BRAKE", "?", "?");  // NOT NEEDED ANY MORE... DELETE SCRIPT XML




    // ... end expose local device variable

    // ENGINE MASTER SWITCH (MONITOR FOR GAME/CONTROLLER MISMATCH)
    //subscribeData(kENG1_Master_Pos,   MSFS,   String("GENERAL ENG STARTER ACTIVE:1").c_str());
    //subscribeData(kENG2_Master_Pos,   MSFS,    String("GENERAL ENG STARTER ACTIVE:2").c_str());
    //subscribeData(kENG2_Master_Pos,   MSFS,     String(getPStr(String(ipstr_engMasterSwitchPos).c_str()) + "2").c_str());

    //TURBINE_IGNITION_SWITCH_SET1
    //TURBINE_IGNITION_SWITCH_SET2


  }

  // tell SPAD.neXT we are done with config
  messenger.sendCmd(kRequest, "CONFIG");
  isReady = true;


/*
  // SEND as-found state of physical toggle switches in event controller reconnected mid-game
  //messenger.sendCmd(kLOCAL_ENG_MST_STARTER_1, !buttons_1[i].currentVal == 0 ? -1 : 1);
  messenger.sendCmd(kLOCAL_ENG_MST_STARTER_1, !buttons_1[P_DI_ENG_MST_1].currentVal == 1 ? 1 : -1);
  messenger.sendCmd(kLOCAL_ENG_MST_STARTER_2, !buttons_1[P_DI_ENG_MST_2].currentVal == 1 ? 1 : -1);

  messenger.sendCmd(kLOCAL_ENG_MODE_SS_POS_CRANK, buttons_1[P_DI_ENG_MODE_SS1].currentVal == 1 ? 1 : -1);
  messenger.sendCmd(kLOCAL_ENG_MODE_SS_POS_START, buttons_1[P_DI_ENG_MODE_SS2].currentVal == 1 ? 1 : -1);

  messenger.sendCmd(kLOCAL_GND_SPOILER_ARM, buttons_1[P_DI_SPOILER_ARM].currentVal == 1 ? 1 : -1);
  messenger.sendCmd(kLOCAL_ANTISKID,        buttons_2[P_DI_ANTISKID].currentVal == 1 ? 1 : -1);

*/

messenger.sendCmd(kLOCAL_PARK_BRAKE,      buttons_2[P_DI_BRAKE_PARK].currentVal == 1 ? -1 : 1); // value inverted (too lazy to change wiring)

  return;
}
 void exposeLocalDeviceVariable(COMMAND_TYPE cmdID, String path, String varName, String description)
{
    messenger.sendCmdStart(kCommand);
    messenger.sendCmdArg("ADD");
    messenger.sendCmdArg(cmdID);
    messenger.sendCmdArg(path); // will become "SERIAL:<guid>/leds/systemled"
    messenger.sendCmdArg("U8"); // unsigned 8bit data type
    messenger.sendCmdArg("RW"); // read/write
    messenger.sendCmdArg(varName);  // Name?
    messenger.sendCmdArg(description);  // Description
    messenger.sendCmdEnd();

 }

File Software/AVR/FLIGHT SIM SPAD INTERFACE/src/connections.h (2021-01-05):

// Potentioemter inputs
#define P_AI_POT_PFD_ND_FD         A1  // FD/ND/FD brightness
#define P_AI_POT_ECAM              9   // ECAM brightness
#define P_AI_POT_PANEL             8   // panel lighting (overhead, main, pedastool)
#define P_AI_POT_FLOOD             A3  // panel flood lights
#define P_AI_POT_TBD               A0  // TO BE IMPLEMENTED
#define P_AI_POT_SPOILER           A2  // speed brake

/// LED outputs - MCP1
// OUTPUT mcp.digitalWrite() :   {} 0-7=GPA0:GPA7; 8-15=GPB7:GPB0} - BE CAUREFUL ABOUIT REASSIGNING INPUTS. CHECK CODE FOR IMPACT
#define P_DO_FUEL_PMP_CT_1_LED  7   // GPA7 pin 21  PMP 3
#define P_DO_FUEL_PMP_LT_1_LED  6   // GPA6 pin 22  PMP 1
#define P_DO_FUEL_PMP_LT_2_LED  5   // GPA5 pin 23  PMP 2
#define P_DO_EXT_PWR_LED        4 // GPA4 pin xx  EXT PWR
#define P_DO_BTN2_LED           3 // GPA3 pin xx  BTN2  (@TBD)
#define P_DO_BTN1_LED           2 // GPA2 pin xx  BTN1 (@TBD)

#define P_DO_AUTOBRAKE_LO_LED   1   // GPA1 pin xx  AUTOBRK-LO
#define P_DO_AUTOBRAKE_MED_LED  0   // GPA0 pin xx  AUTOBRK-MED
#define P_DO_FUEL_PMP_CT_2_LED  15  //8   // GPB7 pin xx  PMP 4
#define P_DO_FUEL_XFEED_LED     14   // GPB6 pin xx  X-FEED PMP
#define P_DO_FUEL_PMP_RT_1_LED  13  //10  // GPB5 pin xx  PMP 5
#define P_DO_FUEL_PMP_RT_2_LED  12 //14  //11  // GPB4 pin XX  PMP 6
#define P_DO_APU_GEN_LED        9 // B1
#define P_DO_APU_BLEED_LED      8 // B0
#define P_DO_APU_MASTER_LED     11// B3
#define P_DO_APU_STARTER_LED    10  // B2

// SWITCH INDEX POSITIONS - MCP2 (buttons_1)
#define P_DI_PWR_EXT             0 // GPA0
#define P_DI_TBD_2               1 // GPA1 - TO BE IMPLEMENTED
#define P_DI_TBD_1               2 // GPA2 - TO BE IMPLEMENTED
#define P_DI_REV_THRUST_TOG      3 // GPA3
#define P_DI_SPOILER_ARM         4 // GPA4
#define P_DI_AUTOBRAKE_LOW       5 // GPA5
#define P_DI_AUTOBRAKE_MED       6 // GPA6
#define P_DI_AUTOBRAKE_MAX       7 // GPA7
#define P_DI_APU_BLEED           8 // GPB0
#define P_DI_APU_GEN             9 // GPB1
#define P_DI_APU_START          10 // GPB2
#define P_DI_APU_MST            11 // GPB3
#define P_DI_ENG_MST_2          12 // GPB4
#define P_DI_ENG_MST_1          13 // GPB5
#define P_DI_ENG_MODE_SS2       14 // GPB6
#define P_DI_ENG_MODE_SS1       15 // GPB7

// SWITCH INDEX POSITION - MCP3 (buttons_2)
#define P_DO_AUTOBRAKE_MAX_LED      7 // GPA7 (MCP3 ONLY) - SPECIAL CASE!!!
//P_DI_GPA3
#define P_DI_GPA0                   0   // GPA0 - NOT IMPLEMENTED
#define P_DI_GPA1                   1   // GPA1 - NOT IMPLEMENTED
#define P_DI_GPA2                   2   // GPA2 - NOT IMPLEMENTED
#define P_DI_FOOT_BRAKE             3   // GPA3
#define P_DI_ANTISKID               4   // GPA4
#define P_DI_BRAKE_PARK             5   // GPA5 - !!!! IF RE-ASSIGN PIN OR MCP # THEN UPDATE onChangeParkBrake()
#define P_DI_GPA6                   6   // GPA6 - NOT IMPLEMENTED
#define P_DI_GPA7_DO_NOT_USE        7   // GPA7  - !!!!!!!! DO NOT USE!!!!!! USED AS OUTPUT

// NOTE: MCP B REGISTERS MAY BE WIRED IN REVERSE ORDER
#define P_DI_GPB0                  8 // B0 // 15 //B7 //8   // GPB0 - NOT IMPLEMENTED
#define P_DI_FUEL_RT_PMP_2         15 // B7 14 //B6 //9   // GPB1
#define P_DI_FUEL_RT_PMP_1         14 // B6 // 13 //B4+B5 //10  // GPB2
#define P_DI_FUEL_XFEED            13 // B5 // 12 //B4+B5 //11  // GPB3
#define P_DI_FUEL_CT_PMP_2         12 // B4// 11 //B3 //12  // GPB4
#define P_DI_FUEL_LT_PMP_2         11 // B3   // 10 //B2 //13  // GPB5
#define P_DI_FUEL_LT_PMP_1         10 // B2  // 9 //B1 //14  // GPB6
#define P_DI_FUEL_CT_PMP_1         9  // B1 // 8 //B0 //15  // GPB7



#define _CMD_PROVIDER(i) buttons[i].provider ? "MSFS:" + String(getPStr(buttons[i].cmdIndex)) : "SIMCONNECT:" + String(getPStr(buttons[i].cmdIndex))

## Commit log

2021-01-05 Update README.md
    Update valve indices for fuel x-feed pushbutton/LED and ENG MASTER switches due to game update.
2021-01-05 Add files via upload
    Update valve indices due to game update for fuel x-feed (from 1 to 3) pushbutton & LED [main.cpp, digital.cpp]; ENG1 & ENG2 MASTER SWITCH (from 6 & 7 to 1 & 2, respectively) SPAD scripts [ENG1 MASTER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
